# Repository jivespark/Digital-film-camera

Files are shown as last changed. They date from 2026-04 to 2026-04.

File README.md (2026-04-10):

# Digital-film-camera
This is a project I made for the Hackclub stasis YSWS. It is a camera that uses the raspberry pi camera module 3 and a raspberry pi zero to take pictures. I made it be a bit like the older film cameras so you don't get a preview on a screen, only after you took the picture.

**Why did I make this project?**

I made this project since I like photography, and hardware design and thought this would be a nice way to blend them together. I also wanted to have a simple camera I could just slip in my backpack, and don't have to worry about settings, lenses, etc.I usually use my phone for this, but sometimes I just like to leave my phone at home and have a seperate device for taking photos.

Camera assembly:
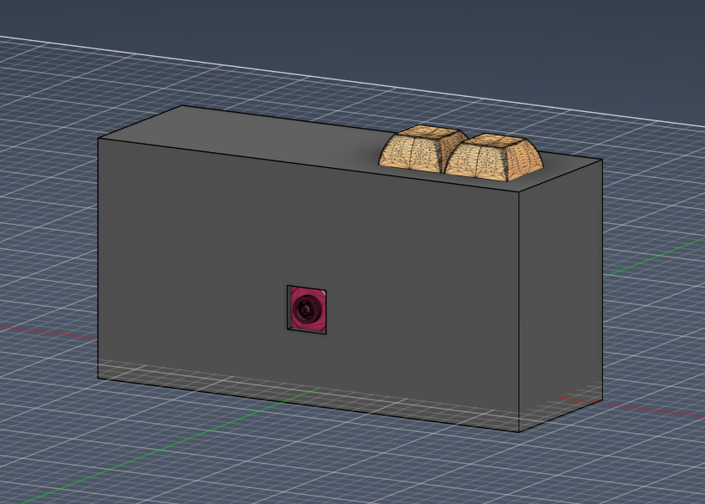
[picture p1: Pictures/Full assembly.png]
Full camera assembly

Internal layout(for assembly):
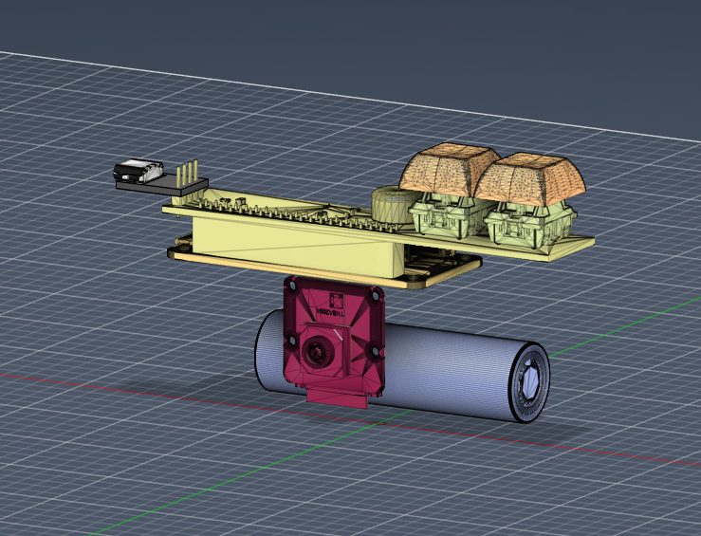
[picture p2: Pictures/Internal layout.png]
Internal layout

Schematic:
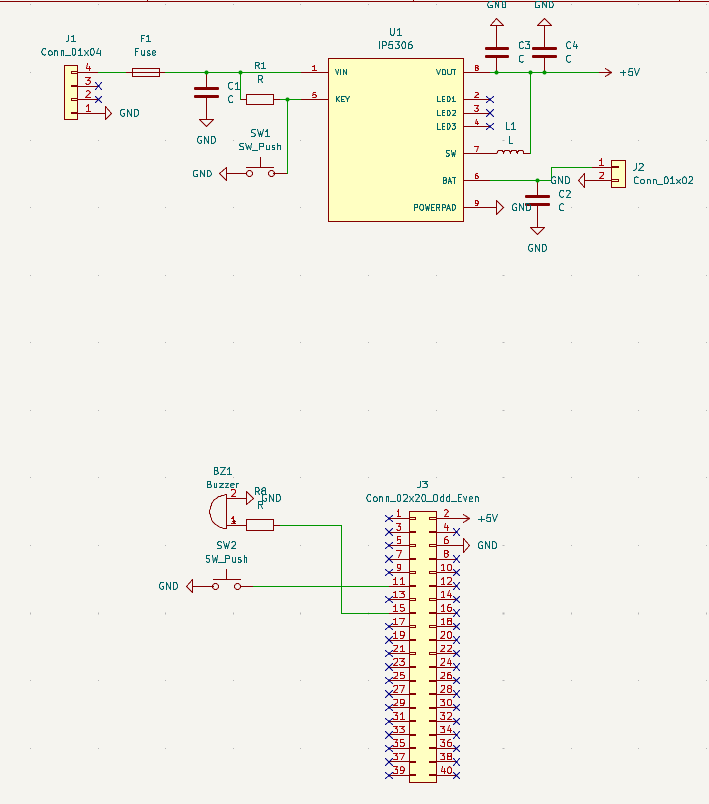
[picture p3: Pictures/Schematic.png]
Schematic

PCB:
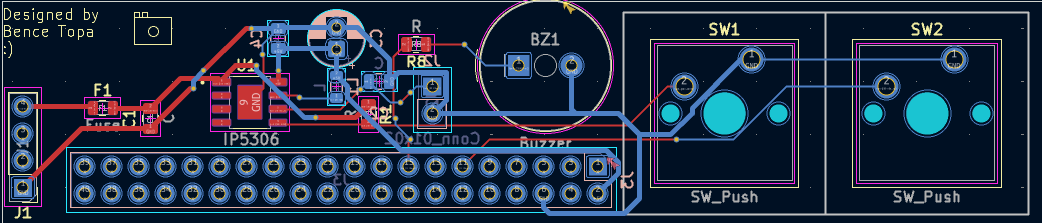
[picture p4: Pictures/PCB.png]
PCB

BOM:
|Name |Purpose |Quantity|Total Cost (USD)|Link |Distributor|
|---|---|---|---|---|---|
|Resistor kit |Resistors for power and buzzer control |1 |6.26 |https://www.aliexpress.com/item/1005009689760726.html|Aliexpress |
|Passive buzzer |A passive buzzer for audio feedback |1 |4.52 |https://www.aliexpress.com/item/1005009689760726.html|Aliexpress |
|Female header |A female header to connect the pi |1 |0.83 |https://www.aliexpress.com/item/32854215610.html |Aliexpress |
|0805 1A 6V fuse |A fuse for safeguarding the power managment |1 |1.48 |https://www.aliexpress.com/item/1005011924342826.html|Aliexpress |
|4.7UH 1210 inductor |Inductor for the power managment circuit |1 |2.76 |https://www.aliexpress.com/item/1005006118890471.html|Aliexpress |
|100µF 25V electrolytic capacitor|A capacitor for voltage regulation |1 |1.26 |https://www.aliexpress.com/item/1005006192445408.html|Aliexpress |
|IP5306 chip |Charging and discharging the battery with boost conversion|1 |1.94 |https://www.aliexpress.com/item/1005007505994153.html|Aliexpress |
|0805 Ceramic capacitors |Ceramic capacitors for power managment. |1 |7.45 |https://www.aliexpress.com/item/1005010516436707.html|Aliexpress |
|15 to 22 pin CSI cable |A CSI cable to connect the pi and the camera |1 |2.17 |https://www.aliexpress.com/item/1005006522239991.html|Aliexpress |
|Raspberry pi camera module 3 |Camera module for taking pictures |1 |32.00 |https://www.amazon.com/n/dp/B0C9PYCV9S/ |Amazon |
|Raspberry pi zero 2WH |The main microcontroller controlling everything |1 |32.99 |https://www.amazon.com/dp/B0GJQMKJ4V |Amazon |
|Usb-c connector |Usb-c connector for charging |1 |4.43 |https://www.aliexpress.com/item/1005010700033077.html|Aliexpress |

I aslo want to say that 2 MX switches and 1 18650 battery is also required, the reason they are not in the BOM is because I have them at home so I can use those and wont have to buy them.

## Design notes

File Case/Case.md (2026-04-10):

**Assembly instructions:**

The case was designed to be made from wood. It is made to be cut out of 5mm thick wood, and later assembled usin wood glue. All sides except the front should be glued together, except the front, for which the best mounting option I found I installing 4 small magnets in the corners, to have an easily removable front plate to reach the SD card slot.

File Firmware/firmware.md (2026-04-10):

**Firmaware instructions:**

This firmware is meant to be used on the raspberry pi. For the pi you should install the Raspberry pi os lite, and I also recommend enableing ssh to be able to run it headless. Also make sure that the camera interface is enabled.

Libraries to install:  
Picamera2, system packages:  
`sudo apt install -y python3-pip python3-picamera2 libcamera-apps`
Python libraries:  
`pip install lgpio gpiozero --break-system-packages`

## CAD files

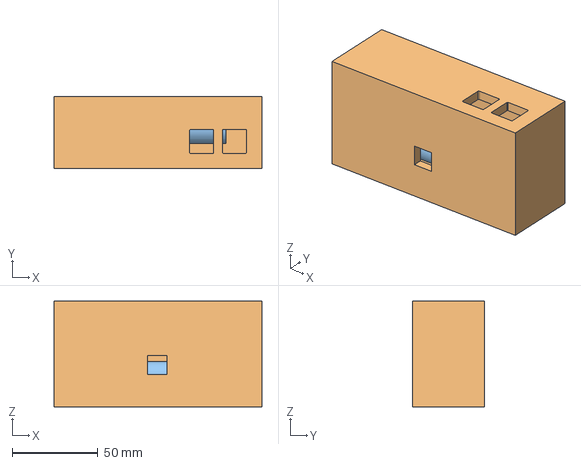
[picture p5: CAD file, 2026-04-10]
Case/Camera_assembly.step
121.0 x 42.0 x 61.5 mm

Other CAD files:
Case/Camera_assembly.f3d

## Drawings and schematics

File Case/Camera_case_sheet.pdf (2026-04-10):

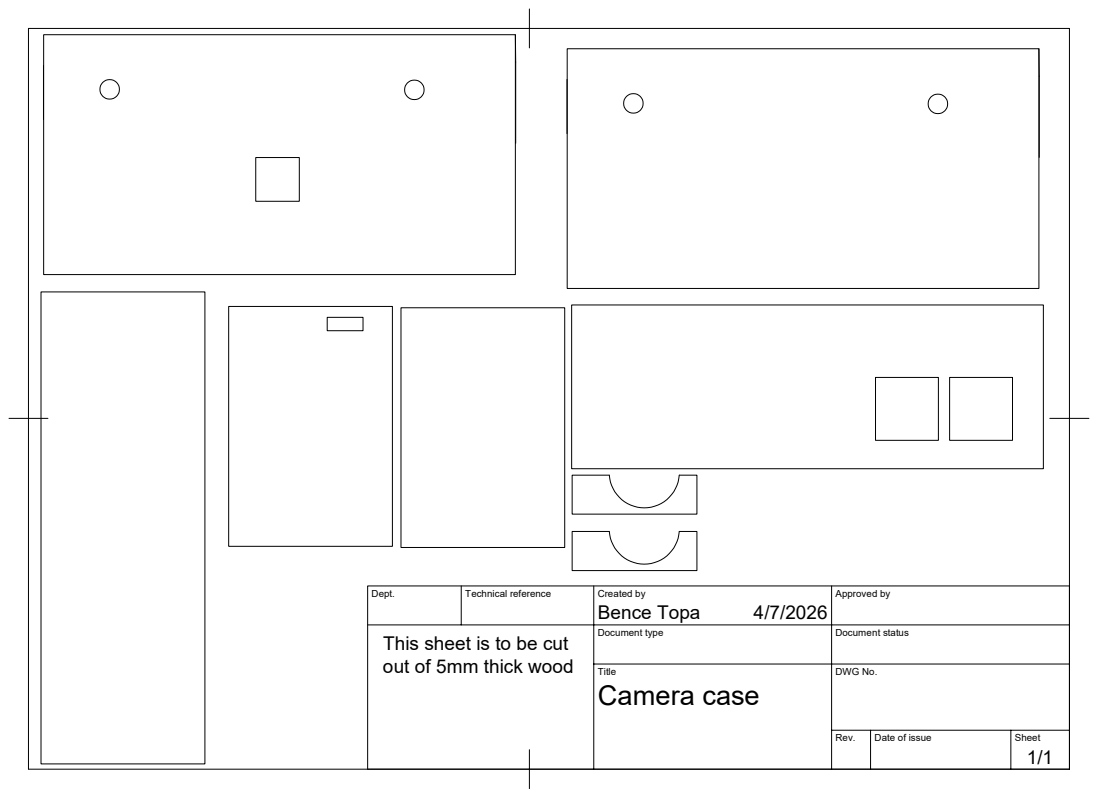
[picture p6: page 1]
Dept.; Technical reference; Created by; Approved by; Document type; Document status; Bence Topa

This sheet is to be cut
out of 5mm thick wood

Title Camera case | DWG No.

Rev. | Date of issue | Sheet 1/1

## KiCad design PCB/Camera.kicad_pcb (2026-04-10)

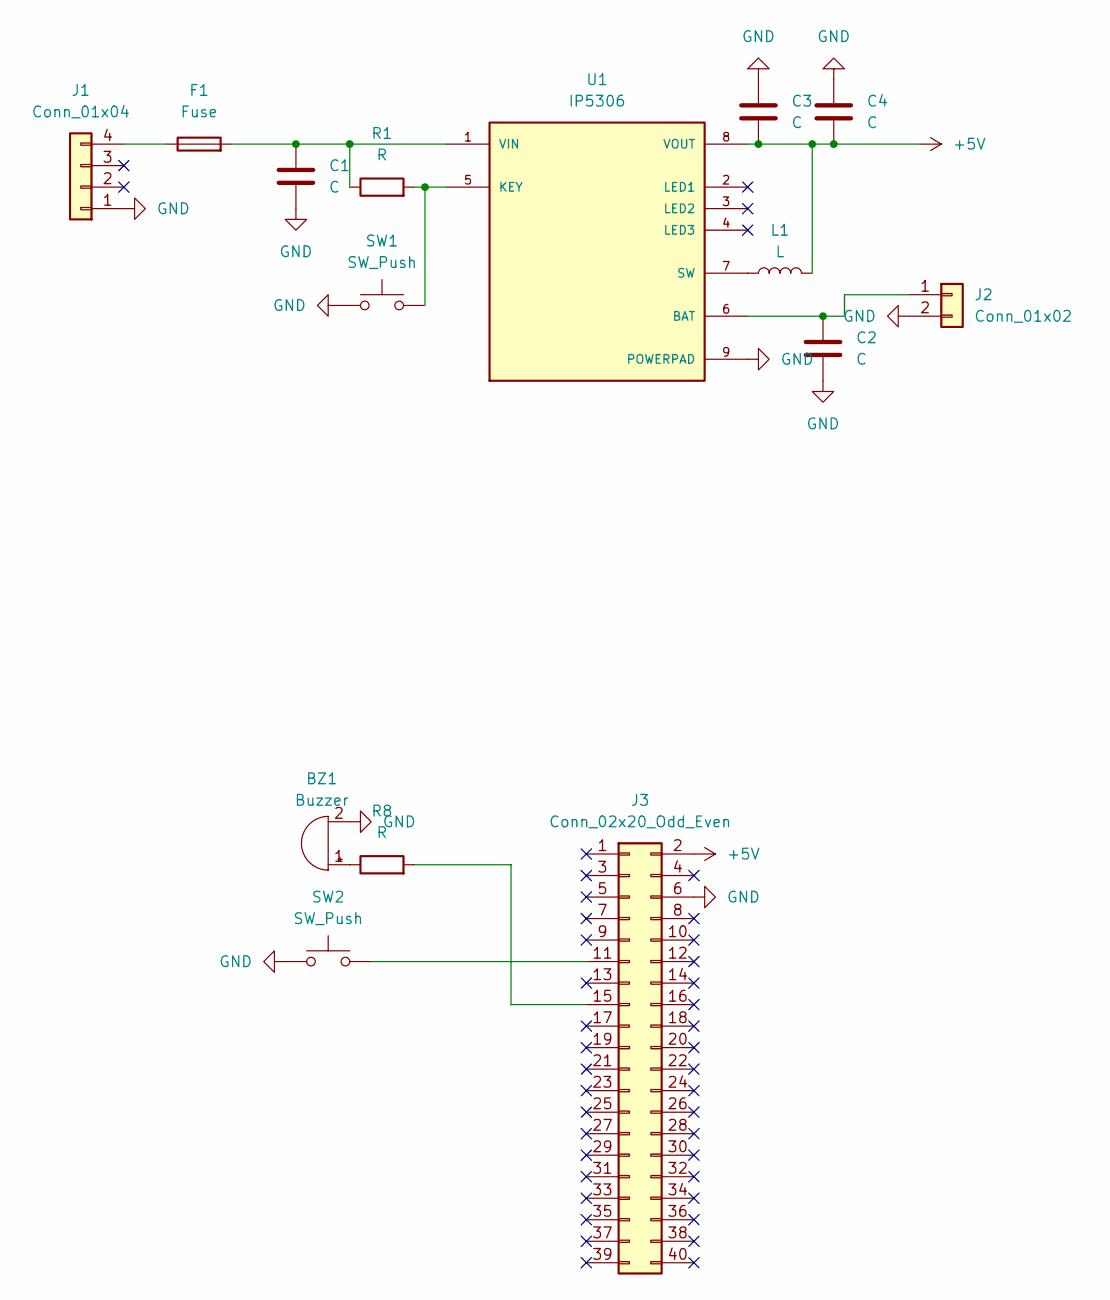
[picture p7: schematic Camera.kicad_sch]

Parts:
BZ1: Buzzer; Buzzer_TDK_PS1240P02BT_D12.2mm_H6.5mm
C1, C2, C4: C; C_0805_2012Metric
C3: C; CP_Radial_D5.0mm_P2.00mm
F1: Fuse; Fuse_0805_2012Metric
J1: Conn_01x04; PinHeader_1x04_P2.54mm_Vertical
J2: Conn_01x02; PinHeader_1x02_P2.54mm_Vertical
J3: Conn_02x20_Odd_Even; PinSocket_2x20_P2.54mm_Vertical
L1: L; L_0805_2012Metric
R1, R8: R; R_0805_2012Metric
SW1, SW2: SW_Push; SW_Cherry_MX_1.00u_PCB
U1: IP5306; SOP127P600X165-9N; PARTREV 1.31

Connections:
+5V: C3.1, C4.2, J3.2, L1.2, U1.8 (VOUT)
GND: BZ1.2 (-), C1.1, C2.2, C3.2, C4.1, J1.1, J2.2, J3.6, SW1.1, SW2.1, U1.9 (POWERPAD)
unnamed: BZ1.1 (+), R8.1
unnamed: F1.1, J1.4
unnamed: C2.1, J2.1, U1.6 (BAT)
unnamed: J3.11, SW2.2
unnamed: J3.15, R8.2
unnamed: R1.2, SW1.2, U1.5 (KEY)
unnamed: L1.1, U1.7 (SW)
unnamed: C1.2, F1.2, R1.1, U1.1 (VIN)

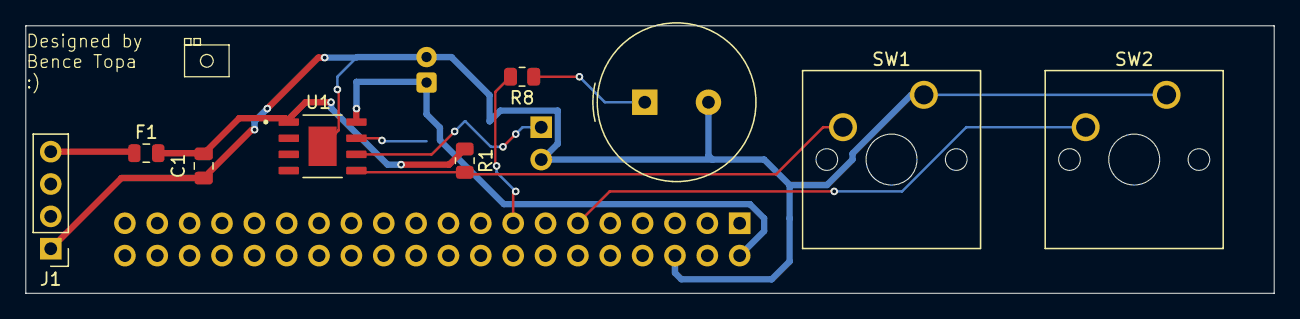
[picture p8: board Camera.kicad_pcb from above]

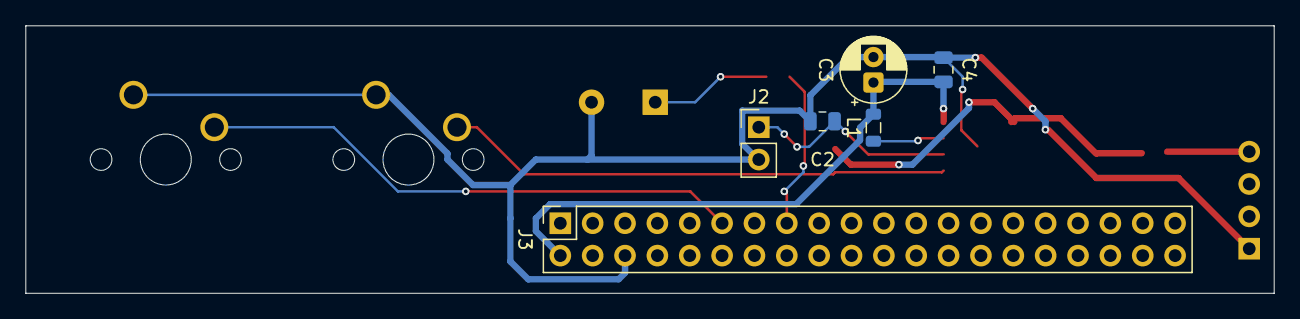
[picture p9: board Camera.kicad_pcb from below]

Board: 2 copper layers, 98.0 x 21.0 mm, 15 parts (6 on the bottom side), 10 nets.

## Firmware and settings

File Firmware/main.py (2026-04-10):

import time
import signal
import sys
from gpiozero import Button
from camera import Camera
from buzzer import startup_sound, shutter_sound, error_sound, low_storage_sound
from storage import setup_storage, next_filename, low_storage

shutter_pin=17

is_capturing=False

print("Starting camera...")
setup_storage()
cam=Camera()
shutter=Button(shutter_pin, bounce_time=0.05)

def take_photo():
    global is_capturing

    if is_capturing:
        return
    
    if low_storage():
        low_storage_sound()
        print("Warning: low storage")
        return
    
    is_capturing=True

    try:
        filepath=next_filename
        print(f"Capturing {filepath}...")
        shutter_sound()
        cam.capture(filepath)
    except Exception as e:
        print(f"Capture error: {e}")
        error_sound()
    finally:
        is_capturing=False

def shutdown(sig, frame):
    print("Shutting down...")
    cam.stop()
    sys.exit(0)

signal.signal(signal.SIGTERM, shutdown)
signal.signal(signal.SIGINT, shutdown)

startup_sound()
print("Camera ready")

shutter.when_pressed=take_photo
signal.pause()

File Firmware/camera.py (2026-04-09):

from picamera2 import Picamera2
import time

class Camera:
    def __init__(self):
        self.cam=Picamera2()
        self.ev=0.0
        self.ready=False
        self._setup()
    
    def _setup(self):
        config=self.cam.create_still_configuration(
            main={"size": (4608, 2592)},
            raw={"size": (4608, 2592)}
        )
        self.cam.configure(config)
        self.cam.set_controls({
            "AeEnable":True,
            "ExposureValue":self.ev,
            "AwbEnable": True,
        })
        self.cam.start()
        time.sleep(2)
        self.ready=True
    
    def capture(self, filepath):
        if(self.ready):
            self.ready=False
            self.cam.capture_file(filepath, name="raw")
            self.ready=True
    
    def stop(self):
        self.cam.stop()

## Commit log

2026-04-09 Add initial implementation of buzzer, camera, main, and storage modules
    [camera.py]
2026-04-10 Added the files for the PCB and the case
    [Camera.kicad_pcb, Camera.kicad_sch, Digital film camera-bom.csv]
2026-04-10 Added pictures
    [Camera_assembly.f3d, Camera_assembly.step]
